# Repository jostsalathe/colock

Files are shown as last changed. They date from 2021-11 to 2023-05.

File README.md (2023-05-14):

# Colock
A USB powered RGB wall clock inspired by analog clocks

## Parts

| Part | Count | Refs | JLCPCB # ***extended*** |
| --- | --- | --- | --- |
| 100nF | 61 | C1...60, C63 | C14663 |
| 10uF | 2 | C61, C62 | C19702 |
| SK6812SIDE-A-RVS | 60 | LED1...60 | ***C2890037*** |
| TYPE-C-31-M-17 | 1 | J15 | ***C283540*** |
| AO3400A | 1 | Q1 | C20917 |
| 0R | 1 | R1 | C21189 |
| 2k2 | 1 | R2 | C4190 |
| 10k | 4 | R3...6 | C25804 |
| 5k1 | 2 | R7, R8 | C23186 |
| AMS1117-3.3 | 1 | U1 | C6186 |

## Assembly

You need two panels with one main segment and five LED segments each to for a full circle by soldering all those segments together.

The panels should look a little something like this (don't mind the missing 3D models):

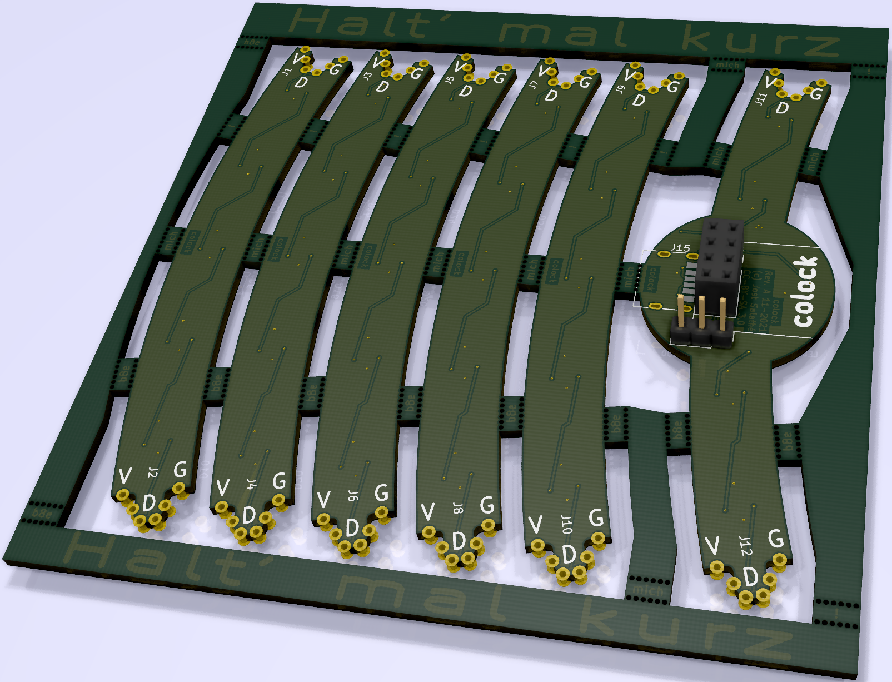
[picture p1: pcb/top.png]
panel top side


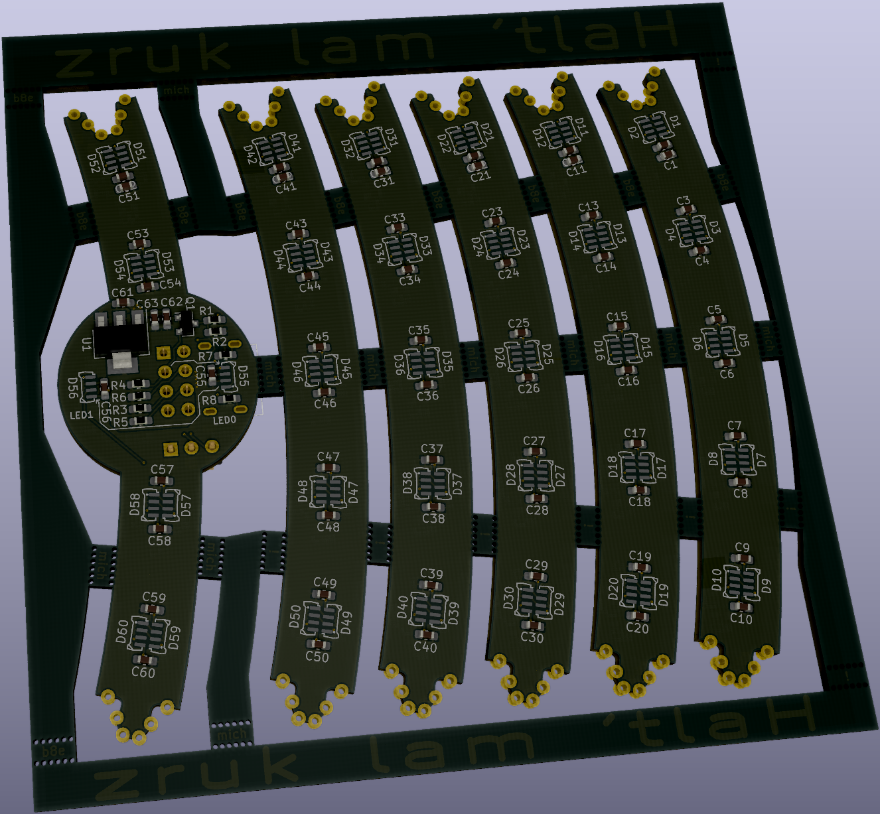
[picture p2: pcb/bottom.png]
panel bottom side


One of the two main segments needs to get the USB-C socket, (optionally the UART header) as well as the ESP-01 Pin-Socket added and the 0 Ohm link R1 removed (if ordered with populated SMD components).

The other main segment may benefit from removing the pullup resistor R2 and the level shifting MOSFET Q1.

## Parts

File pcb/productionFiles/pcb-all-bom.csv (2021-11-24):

Comment | Designator | Footprint | LCSC
100n | C1,C2,C3,C4,C5,C6,C7,C8,C9,C10,C11,C12,C13,C14,C15,C16,C17,C18,C19,C20,C21,C22,C23,C24,C25,C26,C27,C28,C29,C30,C31,C32,C33,C34,C35,C36,C37,C38,C39,C40,C41,C42,C43,C44,C45,C46,C47,C48,C49,C50,C51,C52,C53,C54,C55,C56,C57,C58,C59,C60,C63 | Capacitor_SMD:C_0603_1608Metric_Pad1.08x0.95mm_HandSolder | C14663
10u | C61,C62 | Capacitor_SMD:C_0603_1608Metric_Pad1.08x0.95mm_HandSolder | C19702
WS2812B-4020 | D1,D2,D3,D4,D5,D6,D7,D8,D9,D10,D11,D12,D13,D14,D15,D16,D17,D18,D19,D20,D21,D22,D23,D24,D25,D26,D27,D28,D29,D30,D31,D32,D33,D34,D35,D36,D37,D38,D39,D40,D41,D42,D43,D44,D45,D46,D47,D48,D49,D50,D51,D52,D53,D54,D55,D56,D57,D58,D59,D60 | myLibrary:WS2812B-4020 | C965557
puzzle_female | J1,J3,J5,J7,J9,J11 | myLibrary:puzzle_female
Conn_02x04_Odd_Even | J13 | Connector_PinSocket_2.54mm:PinSocket_2x04_P2.54mm_Vertical
Conn_01x03 | J14 | Connector_PinHeader_2.54mm:PinHeader_1x03_P2.54mm_Vertical
USB_C_Receptacle_Power | J15 | myLibrary:USB_C_Receptacle_HRO_TYPE-C-31-M-17 | C283540
puzzle_male | J2,J4,J6,J8,J10,J12 | myLibrary:puzzle_male
AO3400A | Q1 | Package_TO_SOT_SMD:SOT-23 | C20917
0 | R1 | Resistor_SMD:R_0603_1608Metric_Pad1.05x0.95mm_HandSolder | C21189
2k2 | R2 | Resistor_SMD:R_0603_1608Metric_Pad1.05x0.95mm_HandSolder | C4190
10k | R3,R4,R5,R6 | Resistor_SMD:R_0603_1608Metric_Pad1.05x0.95mm_HandSolder | C25804
5k1 | R7,R8 | Resistor_SMD:R_0603_1608Metric_Pad1.05x0.95mm_HandSolder | C23186
AMS1117-3.3 | U1 | Package_TO_SOT_SMD:SOT-223-3_TabPin2 | C6186

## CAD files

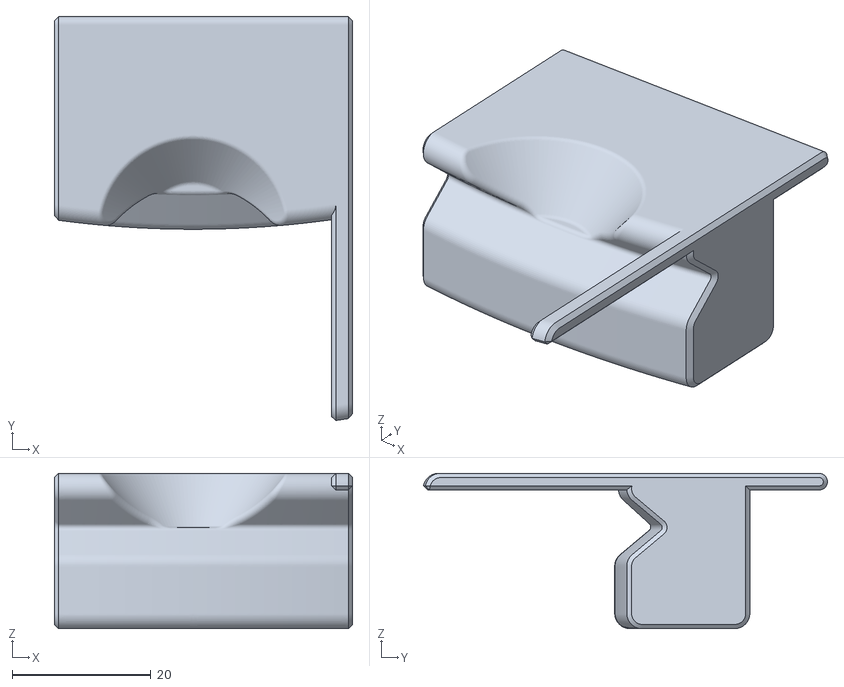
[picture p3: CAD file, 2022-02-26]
tools/ColockSolderClampB.stl
43.0 x 58.3 x 22.4

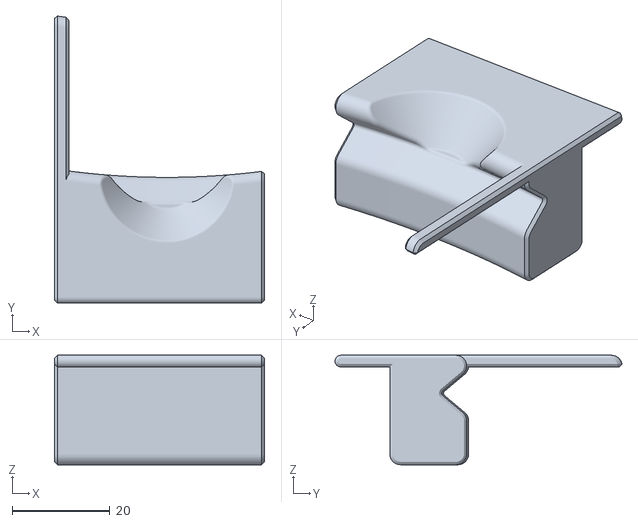
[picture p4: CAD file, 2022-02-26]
tools/ColockSolderClampA.stl
43.0 x 58.7 x 22.4

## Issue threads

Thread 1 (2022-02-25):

Improve Segment interconnect

jostsalathe, 2022-02-25:
A shallow wedge shape for physical mating probably is more suitable.

Electrical contact could be established like this:
- 3 PTH on each side carrying GND, +5V and data signal
- PTHs complemented by soldering pads on both PCB sides facing the mating edge
- Thread wires through the matching PTHs on each side of the interface and twist to fix the two segments in place
- Solder the wires to the pads and PTHs

This should make the assembly a lot simpler and make the connection between segments more mechanically robust. It should also be able to carry more current.

jostsalathe, 2023-05-14:
Apparently this has already been completely implemented with 3dfe526d61dbc13f3064149115dff549b7d423d2. No idea why I never closed this issue...

Closed 2023-05-14.

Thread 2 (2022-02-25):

The WS2812B-4020 apparently are really unreliable

jostsalathe, 2022-02-25:
The first batch ordered at JLCPCB (PCB manufacturing and SMT PCBA of most components) had about 10% of the LEDs dead on arrival.
I suspect that the LED chips either have a really high failure rate from the factory or are quite fragile so they don't survive the PCBA or the transportation between China and Europe.

This is generally in line with my previous experiences regarding the `WS2812B` product line by WorldSemi. The SK68 product family by Dongguan OPSCO Optoelectronics seems to be a lot more robust and reliable. They offer compatible products like `SK 6812 SIDE-A` on their homepage: [opscoled.com/en/product/index.html?sid=13](https://www.opscoled.com/en/product/index.html?sid=13).

They also have Variants that are smaller (`SK 6805 SIDE-G`) or even smaller (`SK 6805-EC3210 R`) or add a white LED chip (`SK 6805 SIDE-F RGBW-WW-P6`). I gravitate to one of the two latter. Additional white would be quite nice but so would be the tiny 3210 package...

jostsalathe, 2022-03-13:
I fiddled around with the data timings using [this great test firmware](https://github.com/bigjosh/SimpleNeoPixelDemo) on an Arduino Nano while consulting [this fantastic article about WS2812B timings](https://wp.josh.com/2014/05/13/ws2812-neopixels-are-not-so-finicky-once-you-get-to-know-them/) but I unfortunately was not able to get successful data transmission to all 120 LEDs whatever I did to the timings.

At this point I give up on that type of LEDs. I think I'll check out `SK 6812 SIDE-A`.

jostsalathe, 2022-03-14:
Some more investigation with a logic analyzer raised the suspicion that there _may_ also be a power delivery problem with presumably the segment interconnect. The contact cross section of the current solution probably is neither that great nor that consistent so #1 should greatly improve on that.

I probably should also lean towards the `5 mA` variants of the `SK 68` family to reduce the max current draw a bit... Still unsure if the `5 mA` refers to a single color or the whole package. I suspect `5 mA` per chip which would mean `15 mA x 120 = 1.8 A`  (or `20 mA x 120 = 2.4A` for RGBW variants) which is more or less reasonable, I guess.

jostsalathe, 2023-05-13:
[JLCPCB](https://jlcpcb.com/parts) offers the following variants of SK 68XX SIDE LEDs:
* `SK6812SIDE-A` (`C5378721`) is the basis for the current footprint design (44e4420a77ac9b469bbdeaa6783c847538c6f4dc) but is not in stock
* `SK6812SIDE-A-RVS` (`C2890037`) has the same footprint as `SK6812SIDE-A`
* `SK6805SIDE-S` (`C2909057`) has a considerably different footprint and is really flat and wide so I suspect that the individual colors are more spread out in the package and maybe mix less nicely
* `SK6805SIDE-G-001` (`C2909060`) is only available for standard PCBA and not for economic

So I'm gonna go with the 12 mA A-RVS variant and just dim the lights more in software... This probably also makes the software more compatible with the APA106 LEDs that probably have a light output more similar to the SK6812 than the SK6805.

jostsalathe, 2023-05-14:
The changes are reflected in the new README and Layout of commit eb1d6db0c4d97f9ff2cdd2f8c11dac122732fe76.

Closed 2023-05-14.

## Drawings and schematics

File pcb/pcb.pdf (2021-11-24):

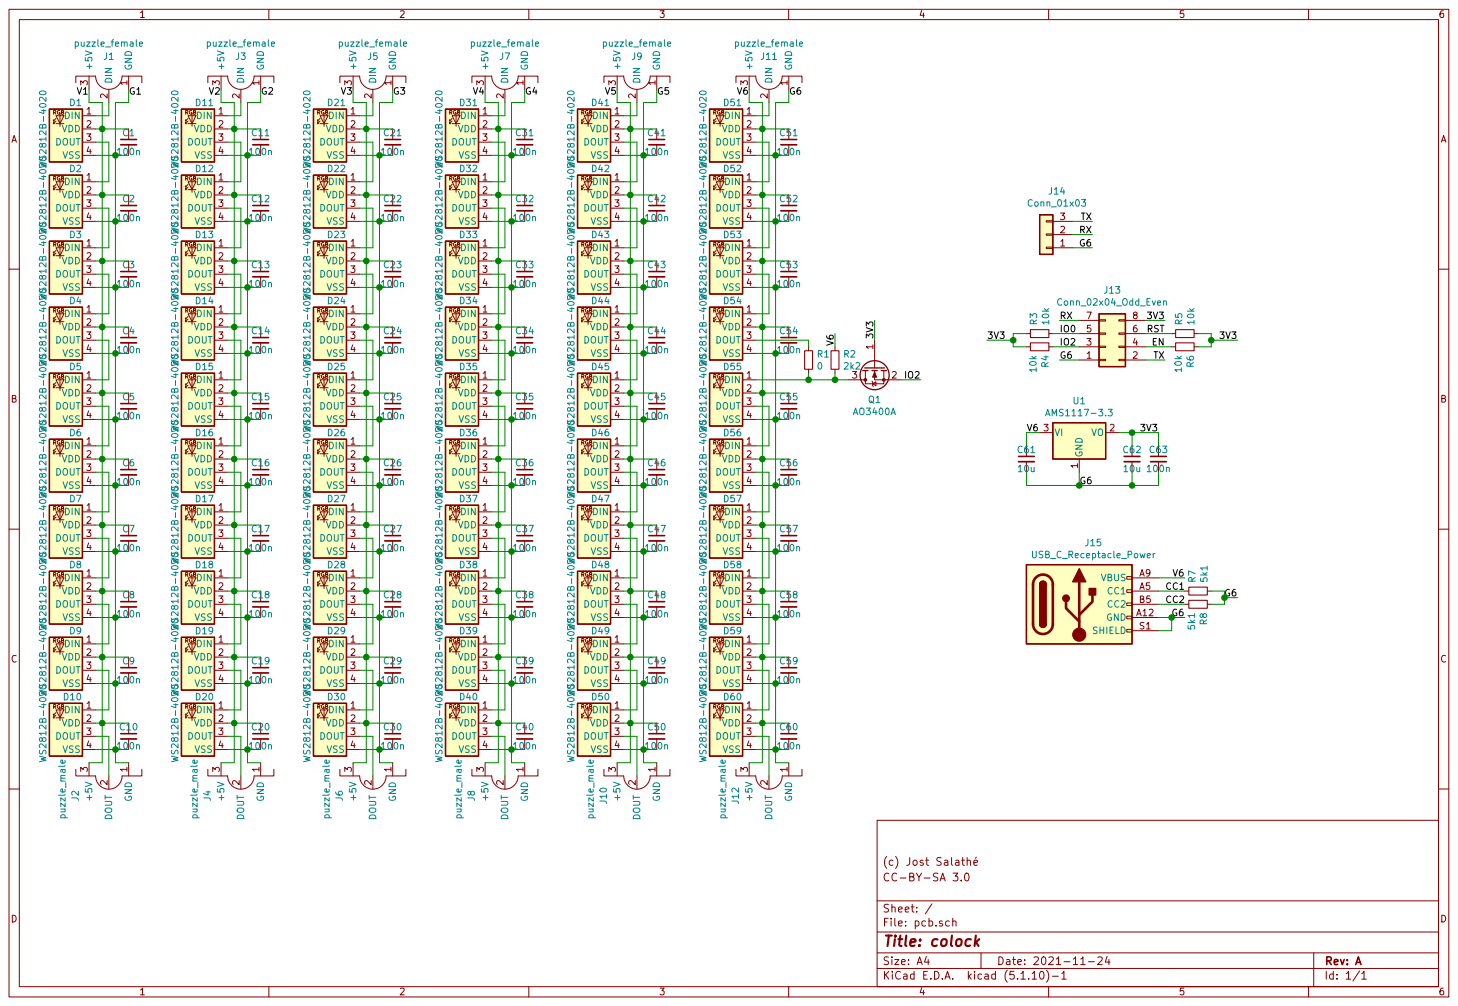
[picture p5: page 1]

(c) Jost Salathé
File: pcb.sch Sheet: / CC-BY-SA 3.0

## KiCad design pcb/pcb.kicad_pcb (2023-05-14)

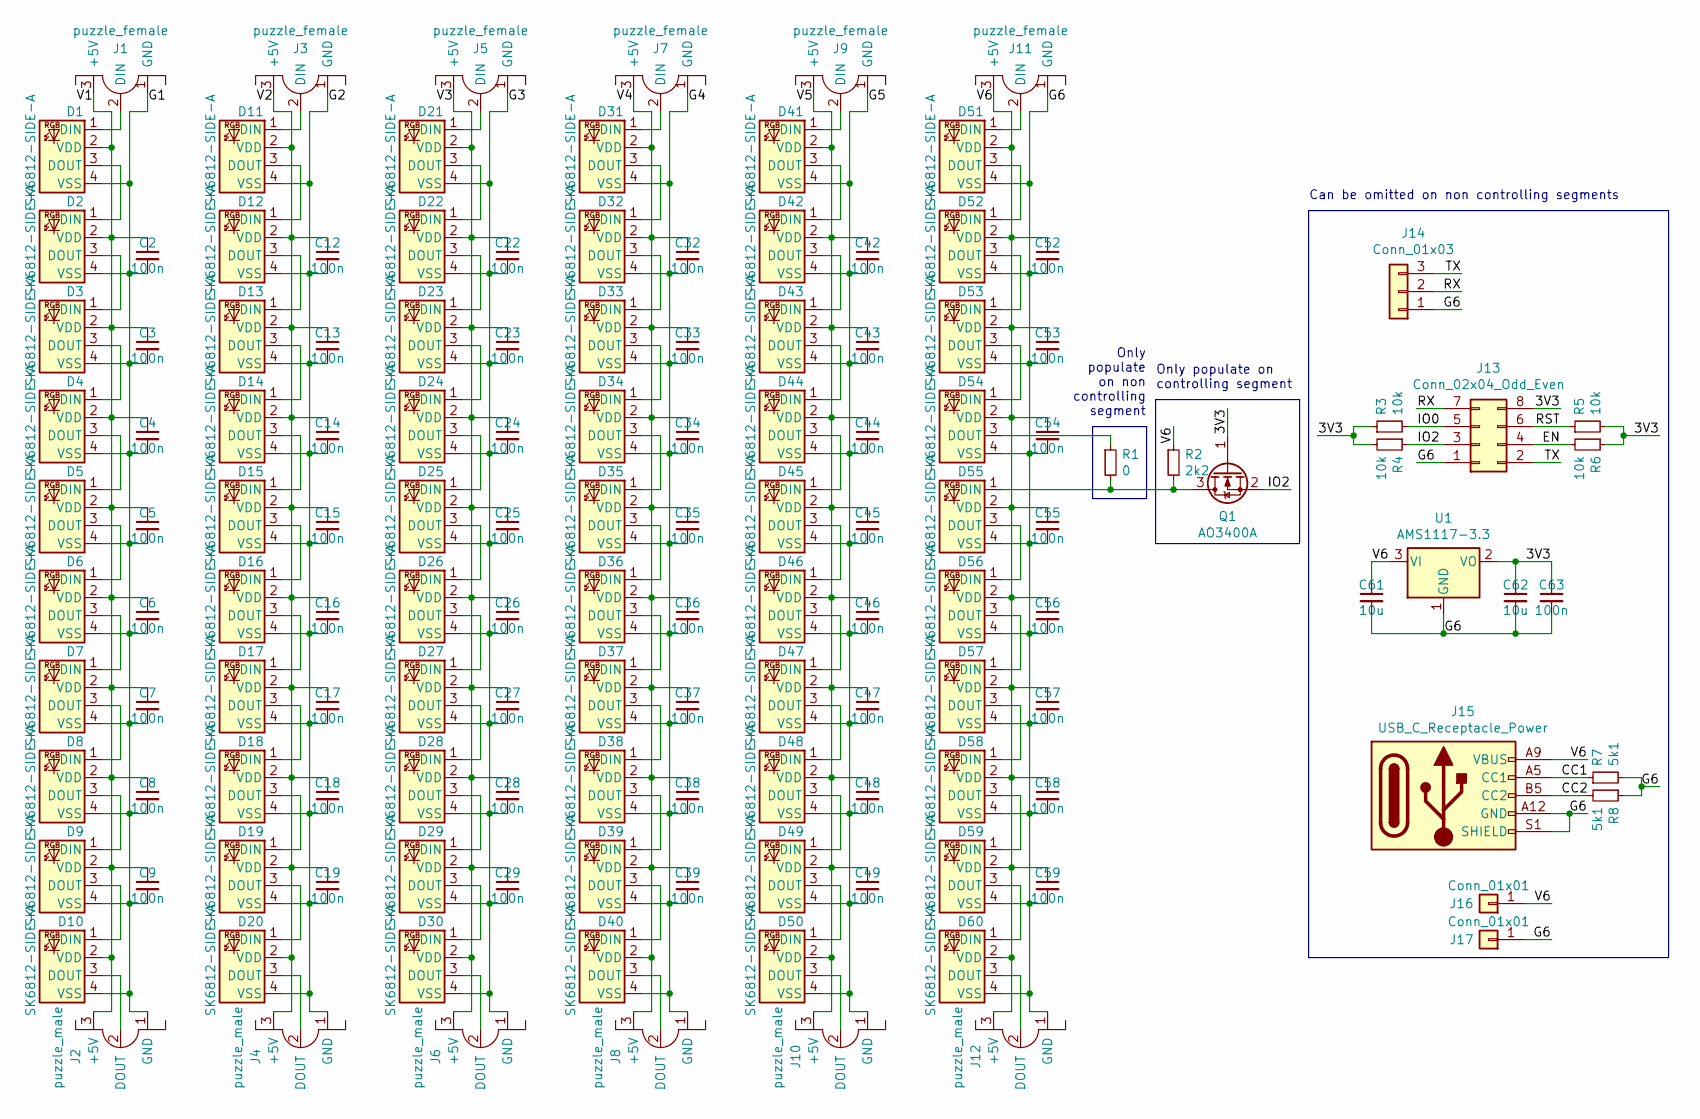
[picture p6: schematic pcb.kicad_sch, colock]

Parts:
C2, C3, C4, C5, C6, C7, C8, C9, C12, C13, C14, C15, C16, C17, C18, C19, C22, C23, C24, C25, C26, C27, C28, C29, C32, C33, C34, C35, C36, C37, C38, C39, C42, C43, C44, C45, C46, C47, C48, C49, C52, C53, C54, C55, C56, C57, C58, C59, C63: 100n; C_0603_1608Metric_Pad1.08x0.95mm_HandSolder
C61, C62: 10u; C_0603_1608Metric_Pad1.08x0.95mm_HandSolder
D1, D2, D3, D4, D5, D6, D7, D8, D9, D10, D11, D12, D13, D14, D15, D16, D17, D18, D19, D20, D21, D22, D23, D24, D25, D26, D27, D28, D29, D30, D31, D32, D33, D34, D35, D36, D37, D38, D39, D40, D41, D42, D43, D44, D45, D46, D47, D48, D49, D50, D51, D52, D53, D54, D55, D56, D57, D58, D59, D60: SK6812-SIDE-A; SK6812-SIDE-A_join_APA106-F8
J1, J3, J5, J7, J9, J11: puzzle_female
J2, J4, J6, J8, J10, J12: puzzle_male
J13: Conn_02x04_Odd_Even; PinSocket_2x04_P2.54mm_Vertical
J14: Conn_01x03; PinHeader_1x03_P2.54mm_Vertical
J15: USB_C_Receptacle_Power; USB_C_Receptacle_HRO_TYPE-C-31-M-17
J16, J17: Conn_01x01; TestPoint_Pad_2.5x2.5mm
Q1: AO3400A; SOT-23
R1: 0; R_0603_1608Metric_Pad1.05x0.95mm_HandSolder
R2: 2k2; R_0603_1608Metric_Pad1.05x0.95mm_HandSolder
R3, R4, R5, R6: 10k; R_0603_1608Metric_Pad1.05x0.95mm_HandSolder
R7, R8: 5k1; R_0603_1608Metric_Pad1.05x0.95mm_HandSolder
U1: AMS1117-3.3; SOT-223-3_TabPin2

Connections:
/3V3: C62.1, C63.1, J13.8, Q1.1 (G), R3.1, R4.2, R5.2, R6.1, U1.2 (VO)
/CC1: J15.A5 (CC1), R7.1
/CC2: J15.B5 (CC2), R8.2
/EN: J13.4, R6.2
/G1: C2.2, C3.2, C4.2, C5.2, C6.2, C7.2, C8.2, C9.2, D1.4 (VSS), D2.4 (VSS), D3.4 (VSS), D4.4 (VSS), D5.4 (VSS), D6.4 (VSS), D7.4 (VSS), D8.4 (VSS), D9.4 (VSS), D10.4 (VSS), J1.1 (GND), J2.1 (GND)
/G2: C12.2, C13.2, C14.2, C15.2, C16.2, C17.2, C18.2, C19.2, D11.4 (VSS), D12.4 (VSS), D13.4 (VSS), D14.4 (VSS), D15.4 (VSS), D16.4 (VSS), D17.4 (VSS), D18.4 (VSS), D19.4 (VSS), D20.4 (VSS), J3.1 (GND), J4.1 (GND)
/G3: C22.2, C23.2, C24.2, C25.2, C26.2, C27.2, C28.2, C29.2, D21.4 (VSS), D22.4 (VSS), D23.4 (VSS), D24.4 (VSS), D25.4 (VSS), D26.4 (VSS), D27.4 (VSS), D28.4 (VSS), D29.4 (VSS), D30.4 (VSS), J5.1 (GND), J6.1 (GND)
/G4: C32.2, C33.2, C34.2, C35.2, C36.2, C37.2, C38.2, C39.2, D31.4 (VSS), D32.4 (VSS), D33.4 (VSS), D34.4 (VSS), D35.4 (VSS), D36.4 (VSS), D37.4 (VSS), D38.4 (VSS), D39.4 (VSS), D40.4 (VSS), J7.1 (GND), J8.1 (GND)
/G5: C42.2, C43.2, C44.2, C45.2, C46.2, C47.2, C48.2, C49.2, D41.4 (VSS), D42.4 (VSS), D43.4 (VSS), D44.4 (VSS), D45.4 (VSS), D46.4 (VSS), D47.4 (VSS), D48.4 (VSS), D49.4 (VSS), D50.4 (VSS), J9.1 (GND), J10.1 (GND)
/G6: C52.2, C53.2, C54.2, C55.2, C56.2, C57.2, C58.2, C59.2, C61.2, C62.2, C63.2, D51.4 (VSS), D52.4 (VSS), D53.4 (VSS), D54.4 (VSS), D55.4 (VSS), D56.4 (VSS), D57.4 (VSS), D58.4 (VSS), D59.4 (VSS), D60.4 (VSS), J11.1 (GND), J12.1 (GND), J13.1, J14.1, J15.A12 (GND), J15.B12 (GND), J15.S1 (SHIELD), J17.1, R7.2, R8.1, U1.1 (GND)
/IO0: J13.5, R3.2
/IO2: J13.3, Q1.2 (S), R4.1
/RST: J13.6, R5.1
/RX: J13.7, J14.2
/TX: J13.2, J14.3
/V1: C2.1, C3.1, C4.1, C5.1, C6.1, C7.1, C8.1, C9.1, D1.2 (VDD), D2.2 (VDD), D3.2 (VDD), D4.2 (VDD), D5.2 (VDD), D6.2 (VDD), D7.2 (VDD), D8.2 (VDD), D9.2 (VDD), D10.2 (VDD), J1.3 (+5V), J2.3 (+5V)
/V2: C12.1, C13.1, C14.1, C15.1, C16.1, C17.1, C18.1, C19.1, D11.2 (VDD), D12.2 (VDD), D13.2 (VDD), D14.2 (VDD), D15.2 (VDD), D16.2 (VDD), D17.2 (VDD), D18.2 (VDD), D19.2 (VDD), D20.2 (VDD), J3.3 (+5V), J4.3 (+5V)
/V3: C22.1, C23.1, C24.1, C25.1, C26.1, C27.1, C28.1, C29.1, D21.2 (VDD), D22.2 (VDD), D23.2 (VDD), D24.2 (VDD), D25.2 (VDD), D26.2 (VDD), D27.2 (VDD), D28.2 (VDD), D29.2 (VDD), D30.2 (VDD), J5.3 (+5V), J6.3 (+5V)
/V4: C32.1, C33.1, C34.1, C35.1, C36.1, C37.1, C38.1, C39.1, D31.2 (VDD), D32.2 (VDD), D33.2 (VDD), D34.2 (VDD), D35.2 (VDD), D36.2 (VDD), D37.2 (VDD), D38.2 (VDD), D39.2 (VDD), D40.2 (VDD), J7.3 (+5V), J8.3 (+5V)
/V5: C42.1, C43.1, C44.1, C45.1, C46.1, C47.1, C48.1, C49.1, D41.2 (VDD), D42.2 (VDD), D43.2 (VDD), D44.2 (VDD), D45.2 (VDD), D46.2 (VDD), D47.2 (VDD), D48.2 (VDD), D49.2 (VDD), D50.2 (VDD), J9.3 (+5V), J10.3 (+5V)
/V6: C52.1, C53.1, C54.1, C55.1, C56.1, C57.1, C58.1, C59.1, C61.1, D51.2 (VDD), D52.2 (VDD), D53.2 (VDD), D54.2 (VDD), D55.2 (VDD), D56.2 (VDD), D57.2 (VDD), D58.2 (VDD), D59.2 (VDD), D60.2 (VDD), J11.3 (+5V), J12.3 (+5V), J15.A9 (VBUS), J15.B9 (VBUS), J16.1, R2.1, U1.3 (VI)
unnamed: D1.1 (DIN), J1.2 (DIN)
unnamed: D1.3 (DOUT), D2.1 (DIN)
unnamed: D2.3 (DOUT), D3.1 (DIN)
unnamed: D3.3 (DOUT), D4.1 (DIN)
unnamed: D4.3 (DOUT), D5.1 (DIN)
unnamed: D5.3 (DOUT), D6.1 (DIN)
unnamed: D6.3 (DOUT), D7.1 (DIN)
unnamed: D7.3 (DOUT), D8.1 (DIN)
unnamed: D8.3 (DOUT), D9.1 (DIN)
unnamed: D9.3 (DOUT), D10.1 (DIN)
unnamed: D10.3 (DOUT), J2.2 (DOUT)
unnamed: D11.1 (DIN), J3.2 (DIN)
unnamed: D11.3 (DOUT), D12.1 (DIN)
unnamed: D12.3 (DOUT), D13.1 (DIN)
unnamed: D13.3 (DOUT), D14.1 (DIN)
unnamed: D14.3 (DOUT), D15.1 (DIN)
unnamed: D15.3 (DOUT), D16.1 (DIN)
unnamed: D16.3 (DOUT), D17.1 (DIN)
unnamed: D17.3 (DOUT), D18.1 (DIN)
unnamed: D18.3 (DOUT), D19.1 (DIN)
unnamed: D19.3 (DOUT), D20.1 (DIN)
unnamed: D20.3 (DOUT), J4.2 (DOUT)
unnamed: D21.1 (DIN), J5.2 (DIN)
unnamed: D21.3 (DOUT), D22.1 (DIN)
unnamed: D22.3 (DOUT), D23.1 (DIN)
unnamed: D23.3 (DOUT), D24.1 (DIN)
unnamed: D24.3 (DOUT), D25.1 (DIN)
unnamed: D25.3 (DOUT), D26.1 (DIN)
unnamed: D26.3 (DOUT), D27.1 (DIN)
unnamed: D27.3 (DOUT), D28.1 (DIN)
unnamed: D28.3 (DOUT), D29.1 (DIN)
unnamed: D29.3 (DOUT), D30.1 (DIN)
unnamed: D30.3 (DOUT), J6.2 (DOUT)
unnamed: D31.1 (DIN), J7.2 (DIN)
unnamed: D31.3 (DOUT), D32.1 (DIN)
unnamed: D32.3 (DOUT), D33.1 (DIN)
unnamed: D33.3 (DOUT), D34.1 (DIN)
unnamed: D34.3 (DOUT), D35.1 (DIN)
unnamed: D35.3 (DOUT), D36.1 (DIN)
unnamed: D36.3 (DOUT), D37.1 (DIN)
unnamed: D37.3 (DOUT), D38.1 (DIN)
unnamed: D38.3 (DOUT), D39.1 (DIN)
unnamed: D39.3 (DOUT), D40.1 (DIN)
unnamed: D40.3 (DOUT), J8.2 (DOUT)
unnamed: D41.1 (DIN), J9.2 (DIN)
unnamed: D41.3 (DOUT), D42.1 (DIN)
unnamed: D42.3 (DOUT), D43.1 (DIN)
unnamed: D43.3 (DOUT), D44.1 (DIN)
unnamed: D44.3 (DOUT), D45.1 (DIN)
unnamed: D45.3 (DOUT), D46.1 (DIN)
unnamed: D46.3 (DOUT), D47.1 (DIN)
unnamed: D47.3 (DOUT), D48.1 (DIN)
unnamed: D48.3 (DOUT), D49.1 (DIN)
unnamed: D49.3 (DOUT), D50.1 (DIN)
unnamed: D50.3 (DOUT), J10.2 (DOUT)
unnamed: D51.1 (DIN), J11.2 (DIN)
unnamed: D51.3 (DOUT), D52.1 (DIN)
unnamed: D52.3 (DOUT), D53.1 (DIN)
unnamed: D53.3 (DOUT), D54.1 (DIN)
unnamed: D54.3 (DOUT), R1.1
unnamed: D55.1 (DIN), Q1.3 (D), R1.2, R2.2
unnamed: D55.3 (DOUT), D56.1 (DIN)
unnamed: D56.3 (DOUT), D57.1 (DIN)
unnamed: D57.3 (DOUT), D58.1 (DIN)
unnamed: D58.3 (DOUT), D59.1 (DIN)
unnamed: D59.3 (DOUT), D60.1 (DIN)
unnamed: D60.3 (DOUT), J12.2 (DOUT)

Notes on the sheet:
Only populate on controlling segment
Can be omitted on non controlling segments
Only populate on non controlling segment

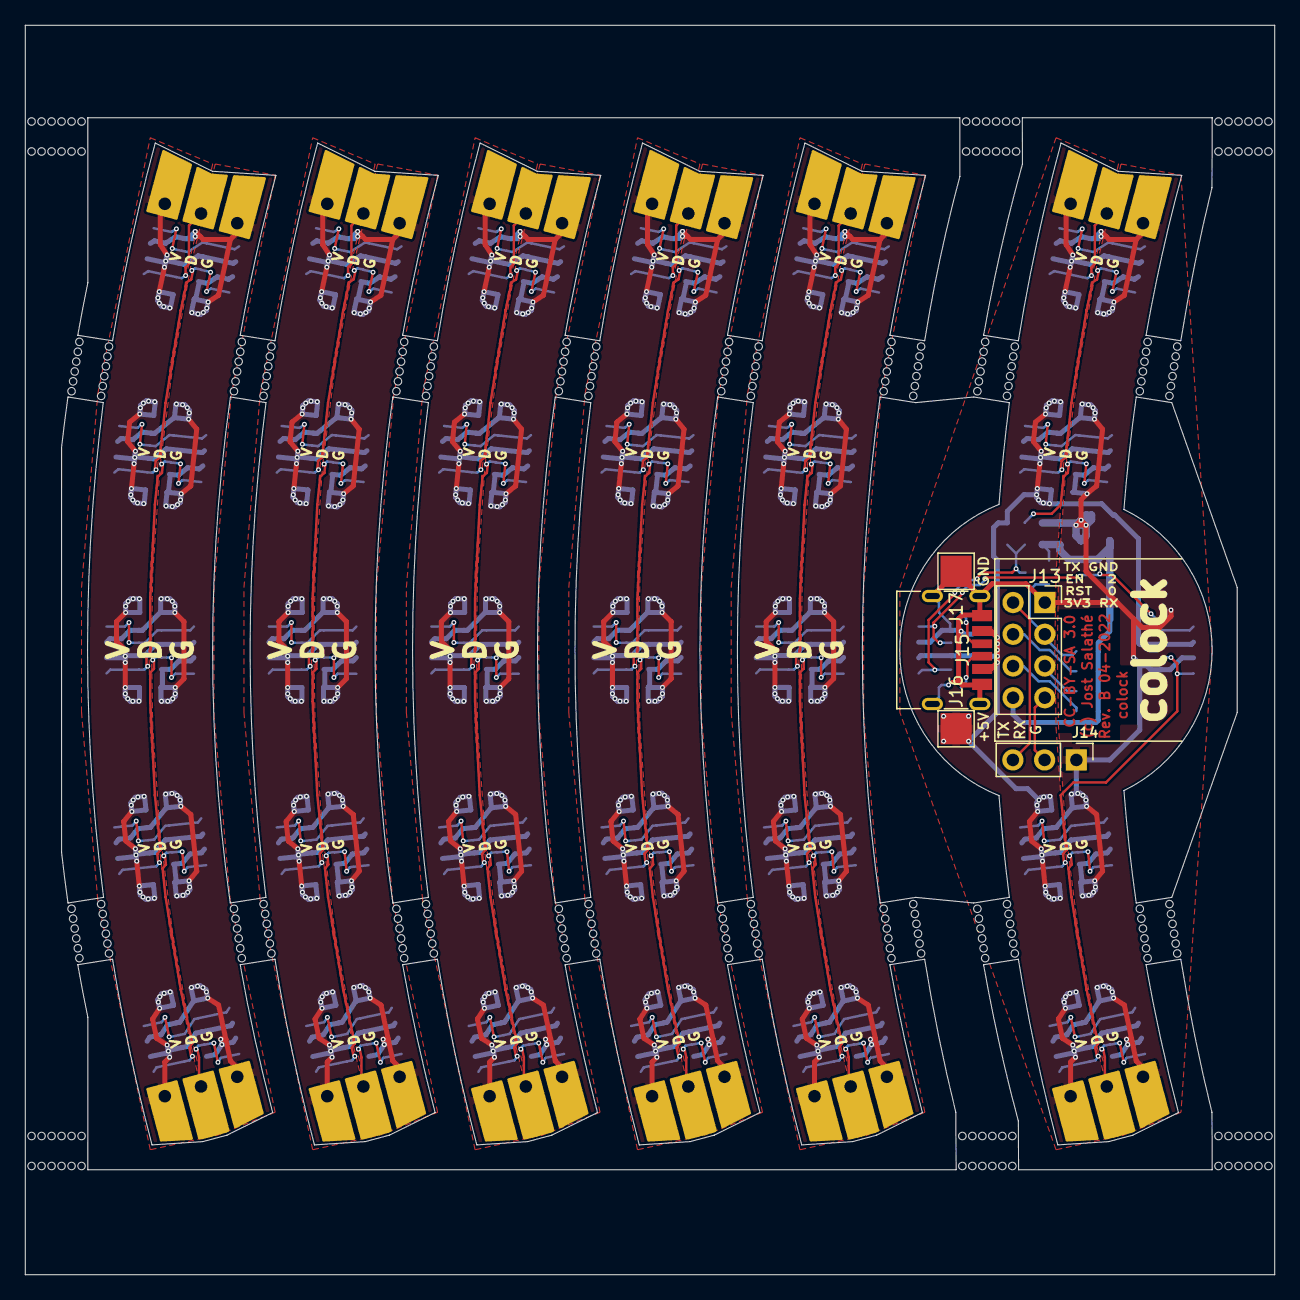
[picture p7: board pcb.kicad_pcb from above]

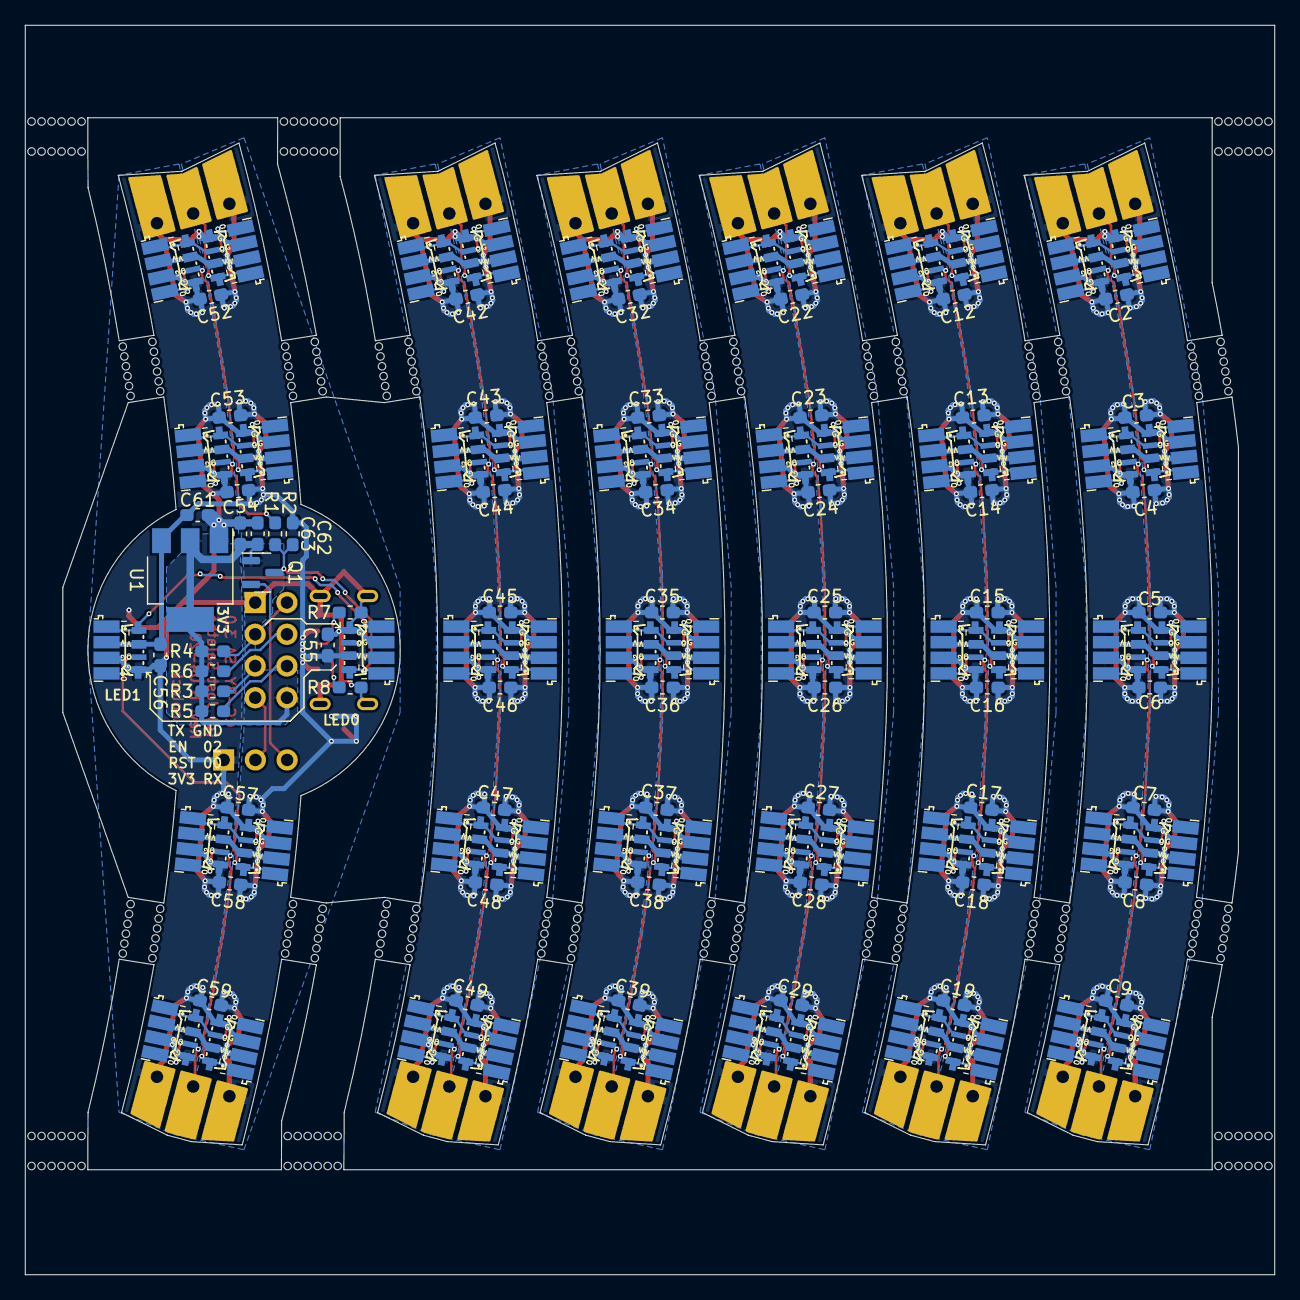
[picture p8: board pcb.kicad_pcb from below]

Board: 2 copper layers, 100.0 x 100.0 mm, 160 parts (121 on the bottom side), 88 nets.

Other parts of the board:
mouse-bite-3mm-slot, mouse-bite-3mm-slot#2, mouse-bite-3mm-slot#3, mouse-bite-3mm-slot#4, mouse-bite-3mm-slot#5, mouse-bite-3mm-slot#6, mouse-bite-3mm-slot#7, mouse-bite-3mm-slot#8, mouse-bite-3mm-slot#9, mouse-bite-3mm-slot#10, mouse-bite-3mm-slot#11, mouse-bite-3mm-slot#12, mouse-bite-3mm-slot#13, mouse-bite-3mm-slot#14, mouse-bite-3mm-slot#15, mouse-bite-3mm-slot#16, mouse-bite-3mm-slot#17, mouse-bite-3mm-slot#18, mouse-bite-3mm-slot#19, mouse-bite-3mm-slot#20, mouse-bite-3mm-slot#21, mouse-bite-3mm-slot#22: VAL**; mouse-bite-3mm-slot

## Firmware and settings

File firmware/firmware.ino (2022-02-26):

#include <LittleFS.h>
#include <ESP8266WiFi.h>
#include <Updater.h>
#include <ArduinoJson.h>
#include <ezTime.h>
#include <NeoPixelBus.h>


//---------------------------------------------------------------------
// configuration parameters

uint16_t dayStart = 8 * 60;
uint8_t brightnessDay[3] = {10,10,10}; //[0...10]
uint16_t dayEnd = 22 * 60;
uint8_t brightnessNight[3] = {1,1,1}; //[0...10]

char ntpUrl[128] = "pool.ntp.org";
char timezoneName[128] = "UTC";

char ssid_sta[128]     = "yourSSID";
char password_sta[128] = "Your WiFi password";


//---------------------------------------------------------------------
// WiFi

byte my_WiFi_Mode = WIFI_OFF;  // WIFI_STA = 1 = Workstation  WIFI_AP = 2  = Accesspoint

const char * ssid_ap = "colock-ap";
const char * password_ap = "colock-ap";

WiFiServer server(80);
WiFiClient client;

#define MAX_PACKAGE_SIZE 2048
char HTML_String[5000];
char HTTP_Header[150];


//---------------------------------------------------------------------
// time variables

Timezone myTZ;


//---------------------------------------------------------------------
// LED variables

#define NUM_LEDS 120
#define LED_PIN 2
NeoPixelBus<NeoGrbFeature, NeoEsp8266Uart1800KbpsMethod> leds(NUM_LEDS, LED_PIN);
// The outer LEDs have even indices (0, 2, 4, ...) 
// The inner LEDs have odd indices (1, 3, 5, ...) 
// This firmware assumes that the first LED sits at the 6 o'clock position and the signal runs counterclockwise.


//---------------------------------------------------------------------
// general variables

enum action_t
{
  ACTION_RESET = 0,
  ACTION_WRITE_CONFIG = 1,
  ACTION_WIFI_SET = 2,
  ACTION_COLOR_SET = 3,
  ACTION_TIME_SET = 4,
  ACTION_NTP_SET = 5
};

enum colorIndex_t
{
  BRIGHT_GREEN = 0,
  BRIGHT_RED = 1,
  BRIGHT_BLUE = 2
};



// forward declarations
void initDisplay();

void initConfig();
void loadConfig();
void saveConfig();

void initTime();
void handleTime();
bool isDayTime();

RgbColor operator+(const RgbColor & lhs, const RgbColor & rhs);
void showEmpty();
void showTime();

void WiFi_Start_STA();
void WiFi_Start_AP();
void WiFi_Traffic();

void make_HTML01();
void make_HTML_update();
void make_HTML_update_success();
void make_HTML_redirectHome(uint8_t delay);

void send_not_found();
void make_header();
void send_HTML();

void strcati(char* tx, int i);
void strcati2(char* tx, int i);
int Pick_Parameter_Zahl(const char * par, char * str);
int Find_End(const char * such, const char * str);
int Find_Start(const char * such, const char * str);
int Pick_Dec(const char * tx, int idx );
int Pick_N_Zahl(const char * tx, char separator, byte n);
int Pick_Hex(const char * tx, int idx );
void Pick_Text(char * tx_ziel, char  * tx_quelle, int max_ziel);
char HexChar_to_NumChar( char c);

void exhibit(const char * tx, int v);
void exhibit(const char * tx, unsigned int v);
void exhibit(const char * tx, unsigned long v);
void exhibit(const char * tx, const char * v);

String cstr2String(const char* cstr);



void setup()
{
  Serial.begin(74880);

  Serial.println("colock startup...");
  
  initDisplay();

  initConfig();

  showEmpty();

  WiFi_Start_STA();
  if (my_WiFi_Mode == WIFI_OFF)
  {
    WiFi_Start_AP();
  }

  initTime();
}

void loop()
{
  WiFi_Traffic();
  handleTime();
  delay(10);
}




void initDisplay()
{
  Serial.println("LEDs init");
  leds.Begin();
  leds.Show();
  /*
  delay(1000);
  leds.fill(leds.Color(10, 10, 10));
  for (int i=0; i < 60;)// ++i)
  {
    Serial.println("LEDs update 10,10,10");
    leds.show();
    delay(100);
  }
  Serial.println("LEDs show clear");
  leds.clear();
  leds.show();
  */
}



void initConfig()
{
  if (LittleFS.begin())
  {
    Serial.println("mounted file system");
    loadConfig();
  }
  else
  {
    Serial.println("failed to mount filesystem - using default configuration.");
  }
}

void loadConfig()
{
  if (LittleFS.exists("/config.json"))
  {
    Serial.println("reading config file");
    File configFile = LittleFS.open("/config.json", "r");
    if (configFile)
    {
      Serial.println("opened config file");
      DynamicJsonDocument jsonDoc(2048);
      auto error = deserializeJson(jsonDoc, configFile);
      serializeJsonPretty(jsonDoc, Serial);
      if (!error)
      {
        Serial.println("\nparsed json");
        dayStart = jsonDoc.getMember("dayStart").as<uint16_t>();
        brightnessDay[0] = jsonDoc.getMember("dRed").as<uint8_t>();
        brightnessDay[1] = jsonDoc.getMember("dGreen").as<uint8_t>();
        brightnessDay[2] = jsonDoc.getMember("dBlue").as<uint8_t>();
        dayEnd = jsonDoc.getMember("dayEnd").as<uint16_t>();
        brightnessNight[0] = jsonDoc.getMember("nRed").as<uint8_t>();
        brightnessNight[1] = jsonDoc.getMember("nGreen").as<uint8_t>();
        brightnessNight[2] = jsonDoc.getMember("nBlue").as<uint8_t>();
        strcpy(timezoneName, jsonDoc.getMember("timezone").as<String>().c_str());
        strcpy(ntpUrl, jsonDoc.getMember("ntpUrl").as<String>().c_str());
        strcpy(ssid_sta, jsonDoc.getMember("ssid").as<String>().c_str());
        strcpy(password_sta, jsonDoc.getMember("password").as<String>().c_str());
      }
      else
      {
        Serial.print("failed to load json config with code ");
        Serial.print(error.c_str());
        Serial.println(" - using default configuration.");
      }
    }
    else
    {
      Serial.println("failed to open /config.json - using default configuration.");
    }
    configFile.close();
  }
  else
  {
    Serial.println("/config.json not present - using default configuration.");
  }
}

void saveConfig()
{
  Serial.println("writing config file");
  File configFile = LittleFS.open("/config.json", "w");
  if (configFile)
  {
    Serial.println("opened config file");
    DynamicJsonDocument jsonDoc(2048);
    jsonDoc["dayStart"] = dayStart;
    jsonDoc["dRed"] = brightnessDay[0];
    jsonDoc["dGreen"] = brightnessDay[1];
    jsonDoc["dBlue"] = brightnessDay[2];
    jsonDoc["dayEnd"] = dayEnd;
    jsonDoc["nRed"] = brightnessNight[0];
    jsonDoc["nGreen"] = brightnessNight[1];
    jsonDoc["nBlue"] = brightnessNight[2];
    jsonDoc["timezone"] = timezoneName;
    jsonDoc["ntpUrl"] = ntpUrl;
    jsonDoc["ssid"] = ssid_sta;
    jsonDoc["password"] = password_sta;
    serializeJsonPretty(jsonDoc, Serial);
    Serial.println("\nfilled json");
    serializeJson(jsonDoc, configFile);
    Serial.println("wrote config file");
  }
  else
  {
    Serial.println("failed to open /config.json.");
  }
  configFile.close();
}





void initTime()
{
  if (my_WiFi_Mode == WIFI_STA)
  {
    setServer(cstr2String(ntpUrl));
    waitForSync();
    setInterval(60 * 60);
    myTZ.setLocation(cstr2String(timezoneName));
  }
  showTime();
}

void handleTime()
{
  events();
  if (secondChanged())
  {
    showTime();
  }
}

bool isDayTime()
{
  uint16_t minuteOfDay = myTZ.minute() + myTZ.hour() * 60;
  return dayStart <= minuteOfDay && minuteOfDay < dayEnd;
}

RgbColor operator+(const RgbColor & lhs, const RgbColor & rhs)
{
  return RgbColor(lhs.R + rhs.R, lhs.G + rhs.G, lhs.B + rhs.B);
}

void showEmpty()
{
  Serial.println("clear LEDs and show");
  leds.ClearTo(0);
  leds.Show();
}

void showTime()
{
  // prepare colors
  const uint8_t br = isDayTime() ? 0x1f : 0x4;

  const RgbColor bgColor(0, 0, 0);
  const RgbColor hColor(0, 0, br);
  const RgbColor mColor(0, br, 0);
  const RgbColor sColor(br, 0, 0);
  const RgbColor hMarkColor(br/2, br/2, br/2);
  const RgbColor mMarkColor(br/4, br/4, br/4);

  // set LEDs and show
  uint8_t second = myTZ.second();
  uint8_t & sPos =second;
  uint8_t minute = myTZ.minute();
  uint8_t & mPos = minute;
  uint8_t hour = myTZ.hour();
  uint8_t hPos = (hour % 12) * 5 + minute / 12;

  uint8_t cursor = 30;
  for (int i=0; i < NUM_LEDS/2; ++i)
  {
    // odd index - inner ring
    RgbColor color = cursor%5 == 0 ? hMarkColor : mMarkColor;
    if (cursor == hPos) color = color + hColor;
    leds.SetPixelColor(i*2+1, color);

    // even index - outer ring
    color = bgColor;
    if (cursor == mPos) color = color + mColor;
    if (cursor == sPos) color = color + sColor;
    leds.SetPixelColor(i*2, color);
    
    // move cursor
    if (cursor == 0) cursor += 60;
    --cursor;
  }

  leds.Show();

  Serial.print("set LEDs and show: ");
  Serial.print(hour);
  Serial.print(":");
  Serial.print(minute);
  Serial.print(":");
  Serial.print(second);
  Serial.print(" ");
  Serial.print(hPos);
  Serial.print(":");
  Serial.print(mPos);
  Serial.print(":");
  Serial.print(sPos);
  Serial.println();
}




//---------------------------------------------------------------------
void WiFi_Start_STA()
{
  unsigned long timeout;

  WiFi.mode(WIFI_STA);
  WiFi.hostname("colock");

  WiFi.begin(ssid_sta, password_sta);
  timeout = millis() + 12000L;
  while (WiFi.status() != WL_CONNECTED
      && millis() < timeout)
  {
    delay(10);
  }

  if (WiFi.status() == WL_CONNECTED)
  {
    server.begin();
    my_WiFi_Mode = WIFI_STA;

    Serial.print("Connected IP - Address : ");
    for (int i = 0; i < 3; i++)
    {
      Serial.print( WiFi.localIP()[i]);
      Serial.print(".");
    }
    Serial.println(WiFi.localIP()[3]);
  }
  else
  {
    WiFi.mode(WIFI_OFF);
    my_WiFi_Mode = WIFI_OFF;
    Serial.println("WiFi connection failed");
  }
}

//---------------------------------------------------------------------
void WiFi_Start_AP()
{
  WiFi.mode(WIFI_AP);
  WiFi.hostname("colock");
  WiFi.softAP(ssid_ap, password_ap);
  server.begin();
  my_WiFi_Mode = WIFI_AP;

  Serial.print("Accesspoint started - Name: \"");
  Serial.print(WiFi.softAPSSID());
  Serial.print("\" password: \"");
  Serial.print(WiFi.softAPPSK());
  Serial.print("\" IP address: ");
  Serial.println(WiFi.softAPIP());
}

//---------------------------------------------------------------------
void WiFi_Traffic()
{
  char my_char;
  int htmlPtr = 0;
  unsigned long my_timeout;

  // Check if a client has connected
  client = server.available();
  if (!client)
  {
    return;
  }

  my_timeout = millis() + 250L;
  while (!client.available() && (millis() < my_timeout) ) delay(10);
  delay(10);
  if (millis() > my_timeout)
  {
    Serial.println("Client connection timeout!");
    return;
  }
  //---------------------------------------------------------------------
  htmlPtr = 0;
  my_char = 0;
  while (client.available() && my_char != '\r')
  {
    my_char = client.read();
    HTML_String[htmlPtr++] = my_char;
  }
  client.flush();
  HTML_String[htmlPtr] = 0;
  Serial.println ("--------------------------------------------------------");
  Serial.print("Remote IP - Address : ");
  for (int i = 0; i < 3; i++)
  {
    Serial.print( client.remoteIP()[i]);
    Serial.print(".");
  }
  Serial.println(client.remoteIP()[3]);

  exhibit("Remote Port ", client.remotePort());
  exhibit("Request : ", HTML_String);

  bool doRestart = false;
  bool reconnect = false;
  
  if (Find_Start("GET / HTTP", HTML_String) >= 0)
  {
    make_HTML01();
  }
  else if (Find_Start("GET /update", HTML_String) >= 0 && Find_Start("HTTP", HTML_String) >= 0)
  {
    make_HTML_update();
  }
  else if (Find_Start("POST /update", HTML_String) >= 0 && Find_Start("HTTP", HTML_String) >= 0)
  {
    send_not_found();//receive and update firmware
    return;
  }
  else if (Find_Start("GET /?", HTML_String) >= 0)
  {
    int myIndex;
    //---------------------------------------------------------------------
    // Benutzereingaben einlesen und verarbeiten
    //---------------------------------------------------------------------
    uint8_t action = Pick_Parameter_Zahl("ACTION=", HTML_String);

    if (action == ACTION_RESET)
    {
      Serial.println("Restarting WiFi chip...");
      doRestart = true;
    }
    else if (action == ACTION_WRITE_CONFIG)
    {
      Serial.println("writing config file...");
      saveConfig();
    }
    else if (action == ACTION_TIME_SET)
    {
      myIndex = Find_End("TIME=", HTML_String);
      if (myIndex >= 0)
      {
        char tmp_time[10]; // TIME=hh:mm:ss
        Pick_Text(tmp_time, &HTML_String[myIndex], 8);
        uint8_t hour = Pick_N_Zahl(tmp_time, ':', 1);
        uint8_t minute = Pick_N_Zahl(tmp_time, ':', 2);

        myIndex = Find_End("DATE=", HTML_String);
        if (myIndex >= 0)
        {
          char tmp_date[12]; // DATE=YYYY-MM-DD
          Pick_Text(tmp_date, &HTML_String[myIndex], 10);
          uint16_t year = Pick_N_Zahl(tmp_date, '-', 1);
          uint8_t month = Pick_N_Zahl(tmp_date, '-', 2);
          uint8_t day = Pick_N_Zahl(tmp_date, '-', 3);
          myTZ.setTime(hour, minute, 0, day, month, year);
          Serial.print("New time: ");
          Serial.print(myTZ.year());
          Serial.print("-");
          Serial.print(myTZ.month());
          Serial.print("-");
          Serial.print(myTZ.day());
          Serial.print(" ");
          Serial.print(myTZ.hour());
          Serial.print(":");
          Serial.print(myTZ.minute());
          Serial.print("\n");
        }
      }
    }
    else if (action == ACTION_NTP_SET)
    {
      myIndex = Find_End("NTPURL=", HTML_String);
      if (myIndex >= 0)
      {
        Pick_Text(ntpUrl, &HTML_String[myIndex], 128);
        exhibit("NTPURL: ", ntpUrl);
        setServer(cstr2String(ntpUrl));
      }
      myIndex = Find_End("TIMEZONE=", HTML_String);
      if (myIndex >= 0)
      {
        Pick_Text(timezoneName, &HTML_String[myIndex], 128);
        myTZ.setLocation(cstr2String(timezoneName));
        exhibit("TIMEZONE: ", myTZ.getTimezoneName().c_str());
      }
      updateNTP();
    }
    else if (action == ACTION_WIFI_SET)
    {
      myIndex = Find_End("SSID=", HTML_String);
      if (myIndex >= 0)
      {
        Pick_Text(ssid_sta, &HTML_String[myIndex], 128);
        exhibit("SSID: ", ssid_sta);
      }
      myIndex = Find_End("PSWD=", HTML_String);
      if (myIndex >= 0)
      {
        Pick_Text(password_sta, &HTML_String[myIndex], 128);
      }
      reconnect = true;
    }
    else if (action == ACTION_COLOR_SET)
    {
      myIndex = Find_End("DAY_START=", HTML_String);
      if (myIndex >= 0)
      {
        char tmp_string[10];
        Pick_Text(tmp_string, &HTML_String[myIndex], 8);
        dayStart = Pick_N_Zahl(tmp_string, ':', 1) * 60 + Pick_N_Zahl(tmp_string, ':', 2);
      }
      brightnessDay[BRIGHT_RED] = Pick_Parameter_Zahl("D_RED=", HTML_String);
      brightnessDay[BRIGHT_GREEN] = Pick_Parameter_Zahl("D_GREEN=", HTML_String);
      brightnessDay[BRIGHT_BLUE] = Pick_Parameter_Zahl("D_BLUE=", HTML_String);
      myIndex = Find_End("DAY_END=", HTML_String);
      if (myIndex >= 0)
      {
        char tmp_string[10];
        Pick_Text(tmp_string, &HTML_String[myIndex], 8);
        dayEnd = Pick_N_Zahl(tmp_string, ':', 1) * 60 + Pick_N_Zahl(tmp_string, ':', 2);
      }
      brightnessNight[BRIGHT_RED] = Pick_Parameter_Zahl("N_RED=", HTML_String);
      brightnessNight[BRIGHT_GREEN] = Pick_Parameter_Zahl("N_GREEN=", HTML_String);
      brightnessNight[BRIGHT_BLUE] = Pick_Parameter_Zahl("N_BLUE=", HTML_String);
    }
    
    showTime();

    //---------------------------------------------------------------------
    //Antwortseite aufbauen
    make_HTML_redirectHome(doRestart ? 3 : 0);
  }
  else
  {
    send_not_found();
    return;
  }

  //---------------------------------------------------------------------
  // Seite senden
  send_HTML();

  if (doRestart)
  {
    Serial.println("Restarting now.");
    ESP.restart();
  }

  if (reconnect)
  {
    WiFi.mode(WIFI_OFF);
    Serial.println("WiFi connection closed - try new parameters");
    WiFi_Start_STA();
    if (my_WiFi_Mode == WIFI_OFF)
    {
      WiFi_Start_AP();
    }
  }
}
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

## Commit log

2021-11-03 messing around
    [pcb.kicad_pcb, pcb.sch]
2021-11-04 tweaked the concepts a little
    [pcb.kicad_pcb, pcb.sch]
2021-11-07 worked on controller schematics
    [pcb.kicad_pcb, pcb.sch]
2021-11-08 Added level shifter for LEDs
    [pcb.sch]
2021-11-09 Done with the layout in general. Mouse bites and edge rails still missing.
    [pcb.kicad_pcb, pcb.sch]
2021-11-15 Added rails and mouse bites for production. Someone with some experience with those should take a look at them before I move on, though...
    [pcb.kicad_pcb]
2021-11-17 Added some text to breakaway tabs and modified mouse bite footprint a little.
    [pcb.kicad_pcb]
2021-11-23 Finishing touches on PCB
    [pcb.kicad_pcb]
2021-11-24 Finalized Rev. A and added production files.
    [pcb-B_Cu.gbl, pcb-B_Mask.gbs, pcb-B_Paste.gbp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]
2022-02-26 Using the ESP8266 Arduino Core v2.6.3, this demo firmware should now compile and work.
2022-02-26 Using the ESP8266 Arduino Core v2.6.3, this demo firmware should now compile and work. This time for realz...
    [ColockSolderClampA.stl, ColockSolderClampB.stl]
2022-02-26 Using NeoPixelBus now because it works properly with newer ESP8266 Arduino Core versions.
2022-03-14 Migrated pcb files to KiCAD 6.
    [pcb.kicad_pcb, pcb.kicad_sch, pcb.sch]
2022-03-14 #1: Reshaped segment interconnects and added solder pads for 5V input.
    [pcb.kicad_pcb, pcb.kicad_sch]
2022-03-15 Worked on SK6812-SIDE-A_join_APA106-F8.kicad_mod
    [pcb.kicad_pcb]
2022-03-15 Worked on footprints.
    [pcb.kicad_pcb, pcb.kicad_sch]
2022-03-16 Cleanup of now obsolete copper traces and areas.
    [pcb.kicad_pcb]
2022-03-16 Redesigned copper areas.
    [pcb.kicad_pcb, pcb.kicad_sch]
2022-03-17 Routing for dumb segments done. Also worked on routing of controller segment.
    [pcb.kicad_pcb]
2023-05-14 finished routing the uC section so now the PCB should be complete. New production files not generated, yet.
    [pcb.kicad_pcb]
